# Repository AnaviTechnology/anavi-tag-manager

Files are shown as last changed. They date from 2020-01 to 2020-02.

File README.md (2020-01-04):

# ANAVI Tag Manager

ANAVI Tag Manager is an open source hardware development board that acts like a WiFi smart gas detector. It features:

* ESP8266 WiFi microcontroller
* Slot for attaching NFC RFID module
* Dedicated slot for I2C OLED display
* Slots for up to 3 plug and play I2C sensors for temperature, barometric pressure, humidity and light
* UART (Universal asynchronous receiver/transmitter) pins for debugging

Open source software for ANAVI Tag Manager written as an Arduino sketch is also available at GitHub](https://github.com/AnaviTechnology/anavi-tag-manager-sw).

# License

The project is released under the [Creative Commons Attribution-ShareAlike 4.0 International (CC BY-SA 4.0)](https://creativecommons.org/licenses/by-sa/4.0/).

Note: This is a human-readable summary of (and not a substitute for) the [license](https://creativecommons.org/licenses/by-sa/4.0/legalcode).

You are free to:

Share — copy and redistribute the material in any medium or format Adapt — remix, transform, and build upon the material for any purpose, even commercially. The licensor cannot revoke these freedoms as long as you follow the license terms. Under the following terms:

Attribution — You must give appropriate credit, provide a link to the license, and indicate if changes were made. You may do so in any reasonable manner, but not in any way that suggests the licensor endorses you or your use. ShareAlike — If you remix, transform, or build upon the material, you must distribute your contributions under the same license as the original. No additional restrictions — You may not apply legal terms or technological measures that legally restrict others from doing anything the license permits. Notices:

You do not have to comply with the license for elements of the material in the public domain or where your use is permitted by an applicable exception or limitation. No warranties are given. The license may not give you all of the permissions necessary for your intended use. For example, other rights such as publicity, privacy, or moral rights may limit how you use the material.

You will have to provide a link to the original creator of the project http://www.anavi.technology on any documentation or website.

Credit can be attributed through a link to the creator website: http://www.anavi.technology

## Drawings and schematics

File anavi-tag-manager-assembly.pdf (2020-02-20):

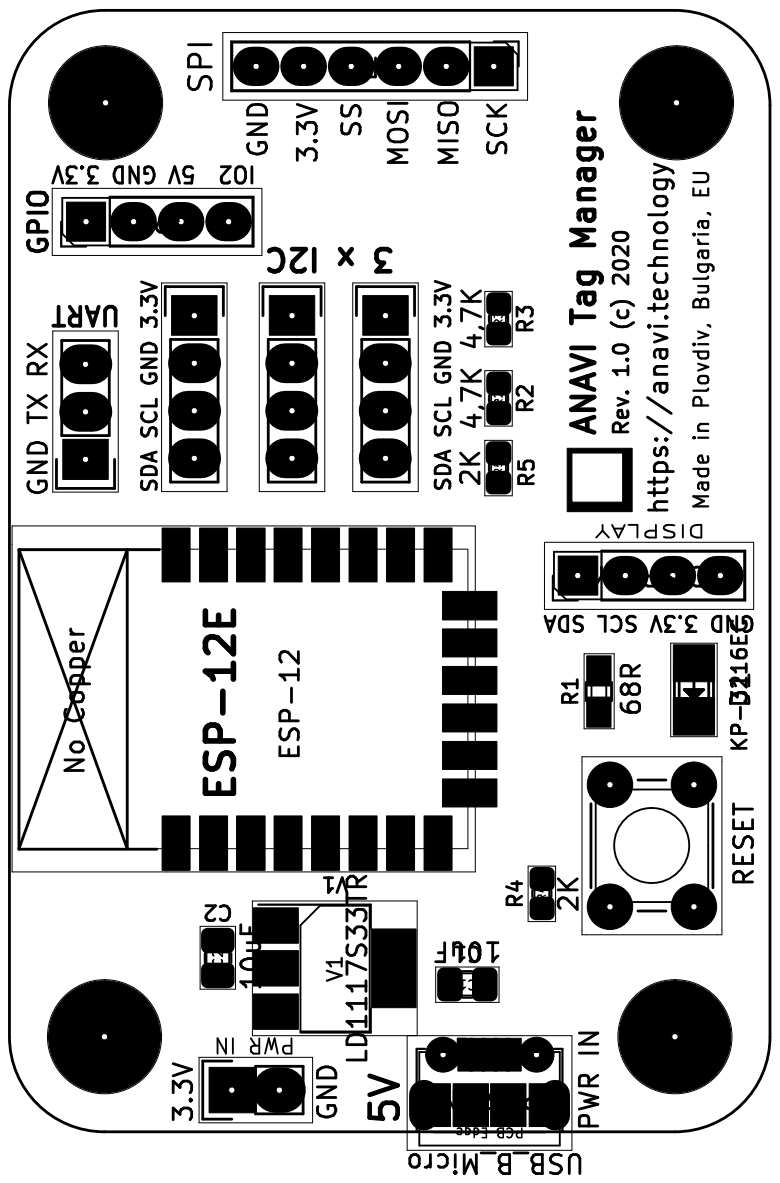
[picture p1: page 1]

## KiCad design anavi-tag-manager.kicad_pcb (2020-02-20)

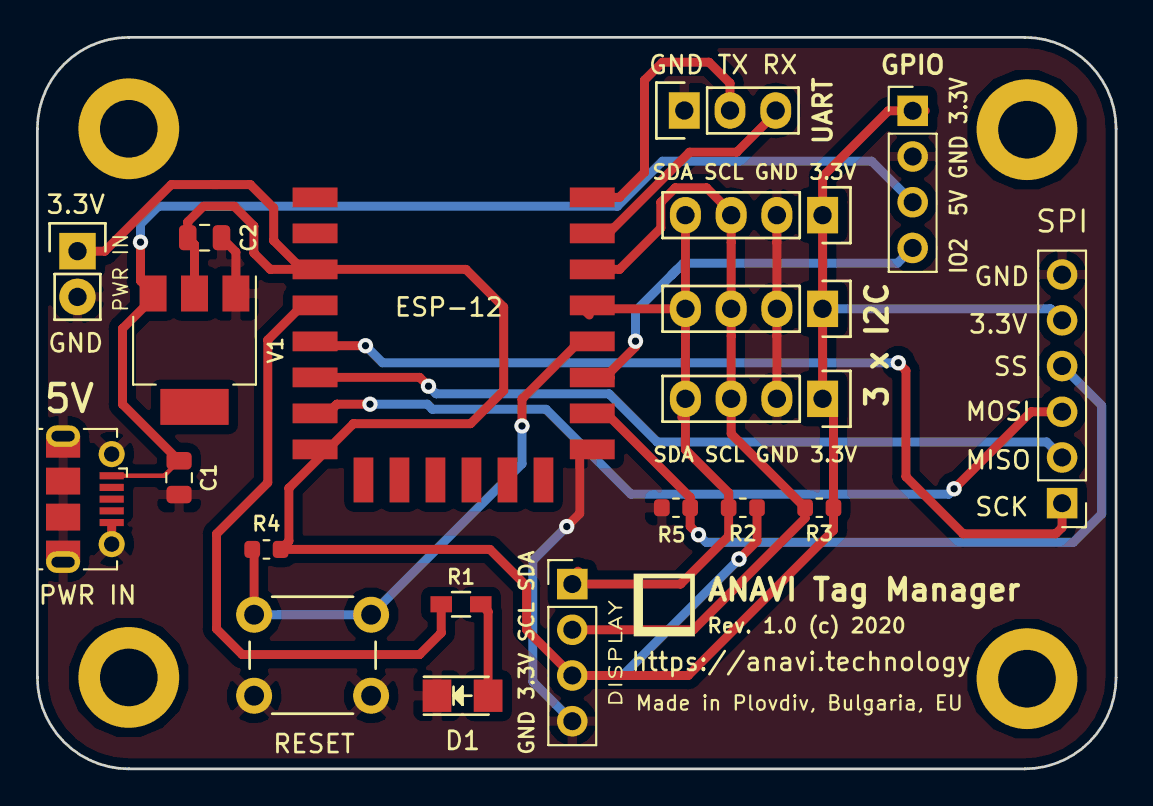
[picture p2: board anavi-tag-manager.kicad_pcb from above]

Board: 2 copper layers, 59.9 x 40.6 mm, 20 parts (0 on the bottom side), 15 nets.

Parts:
C1, C2: 10uF; C_0805_2012Metric
D1: LED; LED_1206
DISPLAY: Conn_01x04; PinHeader_1x04_P2.54mm_Vertical
ESP-12: ESP-12E; ESP-12E_SMD
GPIO: Conn_01x04; PinHeader_1x04_P2.54mm_Vertical
P1: CONN_01X03; Pin_Header_Straight_1x03
PWR IN: USB_B_Micro; USB_Micro-B_Molex-105017-0001
PWR IN#2: Conn_01x02; Pin_Header_Straight_1x02
R1: 68R; R_0603_HandSoldering
R2, R3: 4,7K; R_0603_1608Metric
R4, R5: 2K; R_0603_1608Metric
RESET: SW_DIP_x01; SW_PUSH_6mm_h4.3mm
SPI: Conn_01x06; PinHeader_1x06_P2.54mm_Vertical
U1, U2, U3: I2C_SENS_1; Pin_Header_Straight_1x04
V1: LD1117S33TR; SOT-223

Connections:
+3V3: C2.1, DISPLAY.3, ESP-12.3, ESP-12.8, GPIO.1, PWR IN#2.1, R2.1, R3.1, R4.2, SPI.5, U1.1, U2.1, U3.1, V1.2
+5V: C1.1, GPIO.3, PWR IN.1, V1.3
GND: C1.2, C2.2, D1.1, DISPLAY.4, ESP-12.9, GPIO.2, P1.1, PWR IN.5, PWR IN.6, PWR IN#2.2, R5.2, RESET.1, SPI.6, U1.2, U2.2, U3.2, V1.1
unnamed: D1.2, R1.2
unnamed: ESP-12.4, R1.1
unnamed: ESP-12.5, SPI.1
unnamed: ESP-12.6, SPI.2
unnamed: ESP-12.7, SPI.3
unnamed: ESP-12.10, R5.1, SPI.4
unnamed: ESP-12.11, GPIO.4
unnamed: ESP-12.12, R4.1, RESET.2
unnamed: DISPLAY.1, ESP-12.13, R2.2, U1.4, U2.4, U3.4
unnamed: DISPLAY.2, ESP-12.14, R3.2, U1.3, U2.3, U3.3
unnamed: ESP-12.15, P1.3
unnamed: ESP-12.16, P1.2

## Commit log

2020-01-04 Initial commit
    The design of the printed circuit board for ANAVI Tag Manager
    is based on ANAVI Gas Detector and ANAVI Thermometer.
    [anavi-light-controller-2018-09-18-17-42-49.sch, anavi-light-controller-2018-09-19-00-00-35.sch, anavi-light-controller-2018-09-19-09-35-14.sch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]
2020-01-04 anavi-tag-manager.sch: Modify schematics
    Remove unnecessary components inherited by ANAVI Gas Detector.
    Add 4.7K resistor to GPIO15 of ESP8266. This way it is possible
    to use this pin for SPI communicaiton after booting the board:
    https://github.com/esp8266/Arduino/issues/2466#issuecomment-330794960
    [anavi-tag-manager.sch]
2020-01-04 anavi-tag-manager.sch: Add SPI connector
    Add a connector with 6 pins for SPI.
    [anavi-tag-manager.sch]
2020-01-05 anavi-tag-manager.kicad_pcb: Clear old tracks
    Clear old tracks and prepare for net list import.
    [anavi-tag-manager.kicad_pcb]
2020-01-05 anavi-tag-manager.sch: Add 3.3V & assign footprints
    Add an alternative 3.3V input for power supply from batteries.
    Assign footprints to components.
    [anavi-tag-manager.sch]
2020-01-05 anavi-tag-manager.kicad_pcb: Move components
    Move I2C slots and GPIO pins to save some space.
    [anavi-tag-manager.kicad_pcb]
2020-01-05 anavi-tag-manager.kicad_pcb: Import netlist
    [anavi-tag-manager.kicad_pcb]
2020-01-05 anavi-tag-manager.kicad_pcb: PCB routing
    Apart from the routing, also change the position of GND on the
    GPIO header (with IO2). The new order makes connecting servo
    motors easier because the yellow wire should go to IO2, red wire
    to 5V and black wire to GND.
    [anavi-tag-manager.kicad_pcb, anavi-tag-manager.sch]
2020-01-06 anavi-tag-manager.kicad_pcb: Adjust positions
    Adjust positions of components.
    [anavi-tag-manager.kicad_pcb]
2020-02-20 anavi-tag-manager.kicad_pcb: Set R5 to 2K
    Change R5 value from 4.7K to 2K to ensure that the PN532 NFC
    module will not affect the initial state of GPIO15 on booting.
    [anavi-tag-manager.kicad_pcb]

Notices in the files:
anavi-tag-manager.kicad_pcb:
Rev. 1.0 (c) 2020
